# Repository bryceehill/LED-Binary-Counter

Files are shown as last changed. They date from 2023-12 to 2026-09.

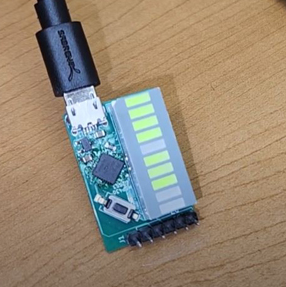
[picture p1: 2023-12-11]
LED_BAR.PNG

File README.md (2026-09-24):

#Introduction

The Montana Tech Binary Counter is a project created by the Electrical Engineering Department.  All files to recreate it are available here.  Potential students can request a binary counter through this link:
https://www.mtech.edu/electrical-engineering/circuit-handout/index.html

To get started plug the binary counter into a computer via a USB cable.  In windows download putty.exe, find the port associated with the counter using "Device Manager" and open that serial port.
Getting started may need some direction.  Watch this video:
https://youtu.be/mpABhzl5tEQ

The current version of the binary counter is the ARM processor version.  You can find all connected files, firmware, designs within this repository.

# LED-Binary-Counter
Public Files for the LED Binary Counter.  Modify, Code, Change, on your own.

There are two versions.  The original one had a MSP430 G2553 as it's controller.  The new version uses an ATSAMD21E15B with added usb utility
Both chips have 10 LEDs that they control.

ARM - ATSAMD21E15B Documentation---------------------------------------------------------------------------

Pinout
PA00 - LED 0
PA01 - LED 1
PA02 - LED 2
PA03 - LED 3
PA04 - LED 4
PA05 - LED 5
PA06 - LED 6
PA07 - LED 7
PA08 - LED 8
PA09 - LED 9
PA16 - PushButton

MSP430 Documentation---------------------------------------------------------------------------------

This respository contains all of the files used to create the Montana Tech LED Bar Graph Counter
The bar graph counter is a piece of SWAG intended for potential students.
There are 10 LEDs controlled by an MSP430 G2553 Microcontroller (TI Look it up)

A PCB was created for use with the QFN-32 package of the G2553
Code was created using code composer studio in C programming language. All files are available
More instructions can be found for new users via the web page:
https://www.mtech.edu/electrical-engineering/circuit-handout/

Potential students can request a free complete system
Pinout of the MSP430 are the following
* 1.0 -
 * 1.1 - RX0  UART Receive
 * 1.2 - TX0  UART Transmit
 * 1.3 - SW1  Pushbutton
 * 1.4 -
 * 1.5 -
 * 1.6 -
 * 1.7 -
 * 2.0 - L8  LED 8
 * 2.1 - L9  LED 9
 * 2.2 -
 * 2.3 -
 * 2.4 -
 * 2.5 -
 * 2.6 -
 * 2.7 -
 * 3.0 - L0  LED 0
 * 3.1 - L1  LED 1
 * 3.2 - L2  LED 2
 * 3.3 - L3  LED 3
 * 3.4 - L4  LED 4
 * 3.5 - L5  LED 5
 * 3.6 - L6  LED 6
 * 3.7 - L7  LED 7

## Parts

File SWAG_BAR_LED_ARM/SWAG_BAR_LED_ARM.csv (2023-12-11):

Source: | C:\Users\CHD\Documents\KiCad\GridLEDv0_1\SWAG_BAR_LED\SWAG_BAR_LED\SWAG_BAR_LED.kicad_sch
Date: | 9/6/2023 4:55:15 PM
Tool: | Eeschema (6.0.1)
Generator: | C:\Program Files\KiCad\6.0\bin\scripting\plugins/bom_csv_grouped_by_value.py
Component Count: | 24
Individual Components:
Item | Qty | Reference(s) | Value | LibPart | Footprint | Datasheet | MANUFACTURER | MAXIMUM_PACKAGE_HEIGHT | PARTREV | STANDARD
 |  | BAR1 | HDSP-4830_2 | LED:HDSP-4830_2 | Display:HDSP-4830 | https://docs.broadcom.com/docs/AV02-1798EN
 |  | C1 | 0.1u | Device:C | Capacitor_SMD:C_0603_1608Metric | ~
 |  | C2 | 0.1u | Device:C | Capacitor_SMD:C_0603_1608Metric | ~
 |  | J1 | Conn_01x06_Male | Connector:Conn_01x06_Male | Connector_PinHeader_2.54mm:PinHeader_1x06_P2.54mm_Vertical | ~
 |  | J3 | USB_B_Micro | Connector:USB_B_Micro | USB:USB_Micro-B_Wuerth_629105150521 | ~
 |  | R1 | 10k | Device:R | Resistor_SMD:R_0603_1608Metric | ~
 |  | R2 | 330 | Device:R | Resistor_SMD:R_0603_1608Metric | ~
 |  | R3 | 330 | Device:R | Resistor_SMD:R_0603_1608Metric | ~
 |  | R4 | 330 | Device:R | Resistor_SMD:R_0603_1608Metric | ~
 |  | R5 | 330 | Device:R | Resistor_SMD:R_0603_1608Metric | ~
 |  | R6 | 330 | Device:R | Resistor_SMD:R_0603_1608Metric | ~
 |  | R7 | 330 | Device:R | Resistor_SMD:R_0603_1608Metric | ~
 |  | R8 | 330 | Device:R | Resistor_SMD:R_0603_1608Metric | ~
 |  | R9 | 330 | Device:R | Resistor_SMD:R_0603_1608Metric | ~
 |  | R10 | 330 | Device:R | Resistor_SMD:R_0603_1608Metric | ~
 |  | R11 | 330 | Device:R | Resistor_SMD:R_0603_1608Metric | ~
 |  | SW1 | PTS636_SM50_SMTR_LFS | SPST_SMD:PTS636_SM50_SMTR_LFS | SW_PTS636_SMT-G_5_CNK | PTS636 SM50 SMTR LFS
 |  | U1 | AP2127N3-1.2 | Regulator_Linear:AP2127N3-1.2 | Package_TO_SOT_SMD:TSOT-23 | https://www.diodes.com/assets/Datasheets/AP2127.pdf
 |  | U2 | SSM6N7002KFU_LF | 2N7002_Dual:SSM6N7002KFU_LF | 6-TSSOP:SOT-363 US6_TOS | SSM6N7002KFU_LF
 |  | U3 | MSP430G2553IRHB32R | MSP430G2553IRHB32R:MSP430G2553IRHB32R | MSP430G2553IRHB32R:IC_MSP430G2553IRHB32R |  | Texas Instruments | 1.00mm | 4223442/B 08/2019 | Manufacturer Recommendations
 |  | U4 | SSM6N7002KFU_LF | 2N7002_Dual:SSM6N7002KFU_LF | 6-TSSOP:SOT-363 US6_TOS | SSM6N7002KFU_LF
 |  | U8 | SSM6N7002KFU_LF | 2N7002_Dual:SSM6N7002KFU_LF | 6-TSSOP:SOT-363 US6_TOS | SSM6N7002KFU_LF
 |  | U9 | SSM6N7002KFU_LF | 2N7002_Dual:SSM6N7002KFU_LF | 6-TSSOP:SOT-363 US6_TOS | SSM6N7002KFU_LF
 |  | U10 | SSM6N7002KFU_LF | 2N7002_Dual:SSM6N7002KFU_LF | 6-TSSOP:SOT-363 US6_TOS | SSM6N7002KFU_LF
Collated Components:
Item | Qty | Reference(s) | Value | LibPart | Footprint | Datasheet | MANUFACTURER | MAXIMUM_PACKAGE_HEIGHT | PARTREV | STANDARD
1 | 1 | BAR1 | HDSP-4830_2 | LED:HDSP-4830_2 | Display:HDSP-4830 | https://docs.broadcom.com/docs/AV02-1798EN
2 | 2 | C1, C2 | 0.1u | Device:C | Capacitor_SMD:C_0603_1608Metric | ~
3 | 1 | J1 | Conn_01x06_Male | Connector:Conn_01x06_Male | Connector_PinHeader_2.54mm:PinHeader_1x06_P2.54mm_Vertical | ~
4 | 1 | J3 | USB_B_Micro | Connector:USB_B_Micro | USB:USB_Micro-B_Wuerth_629105150521 | ~
5 | 1 | R1 | 10k | Device:R | Resistor_SMD:R_0603_1608Metric | ~
6 | 10 | R2, R3, R4, R5, R6, R7, R8, R9, R10, R11 | 330 | Device:R | Resistor_SMD:R_0603_1608Metric | ~
7 | 1 | SW1 | PTS636_SM50_SMTR_LFS | SPST_SMD:PTS636_SM50_SMTR_LFS | SW_PTS636_SMT-G_5_CNK | PTS636 SM50 SMTR LFS
8 | 1 | U1 | AP2127N3-1.2 | Regulator_Linear:AP2127N3-1.2 | Package_TO_SOT_SMD:TSOT-23 | https://www.diodes.com/assets/Datasheets/AP2127.pdf
9 | 5 | U2, U4, U8, U9, U10 | SSM6N7002KFU_LF | 2N7002_Dual:SSM6N7002KFU_LF | 6-TSSOP:SOT-363 US6_TOS | SSM6N7002KFU_LF
10 | 1 | U3 | MSP430G2553IRHB32R | MSP430G2553IRHB32R:MSP430G2553IRHB32R | MSP430G2553IRHB32R:IC_MSP430G2553IRHB32R |  | Texas Instruments | 1.00mm | 4223442/B 08/2019 | Manufacturer Recommendations

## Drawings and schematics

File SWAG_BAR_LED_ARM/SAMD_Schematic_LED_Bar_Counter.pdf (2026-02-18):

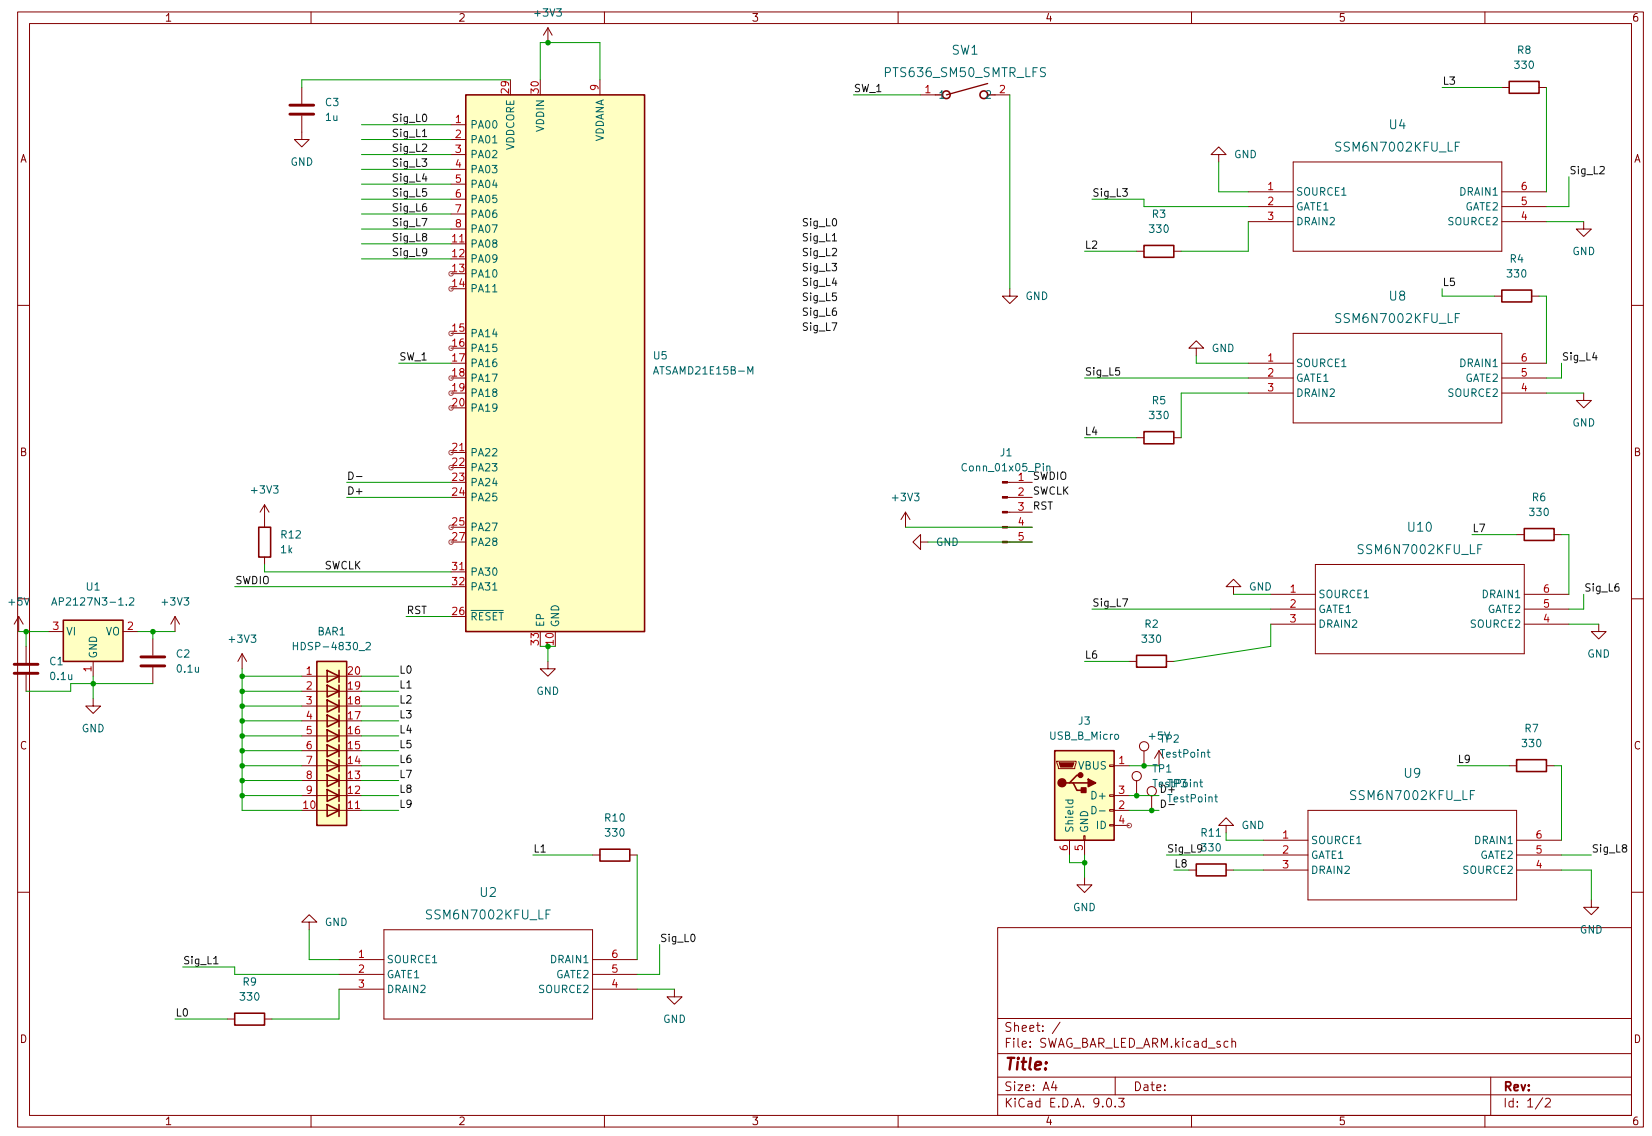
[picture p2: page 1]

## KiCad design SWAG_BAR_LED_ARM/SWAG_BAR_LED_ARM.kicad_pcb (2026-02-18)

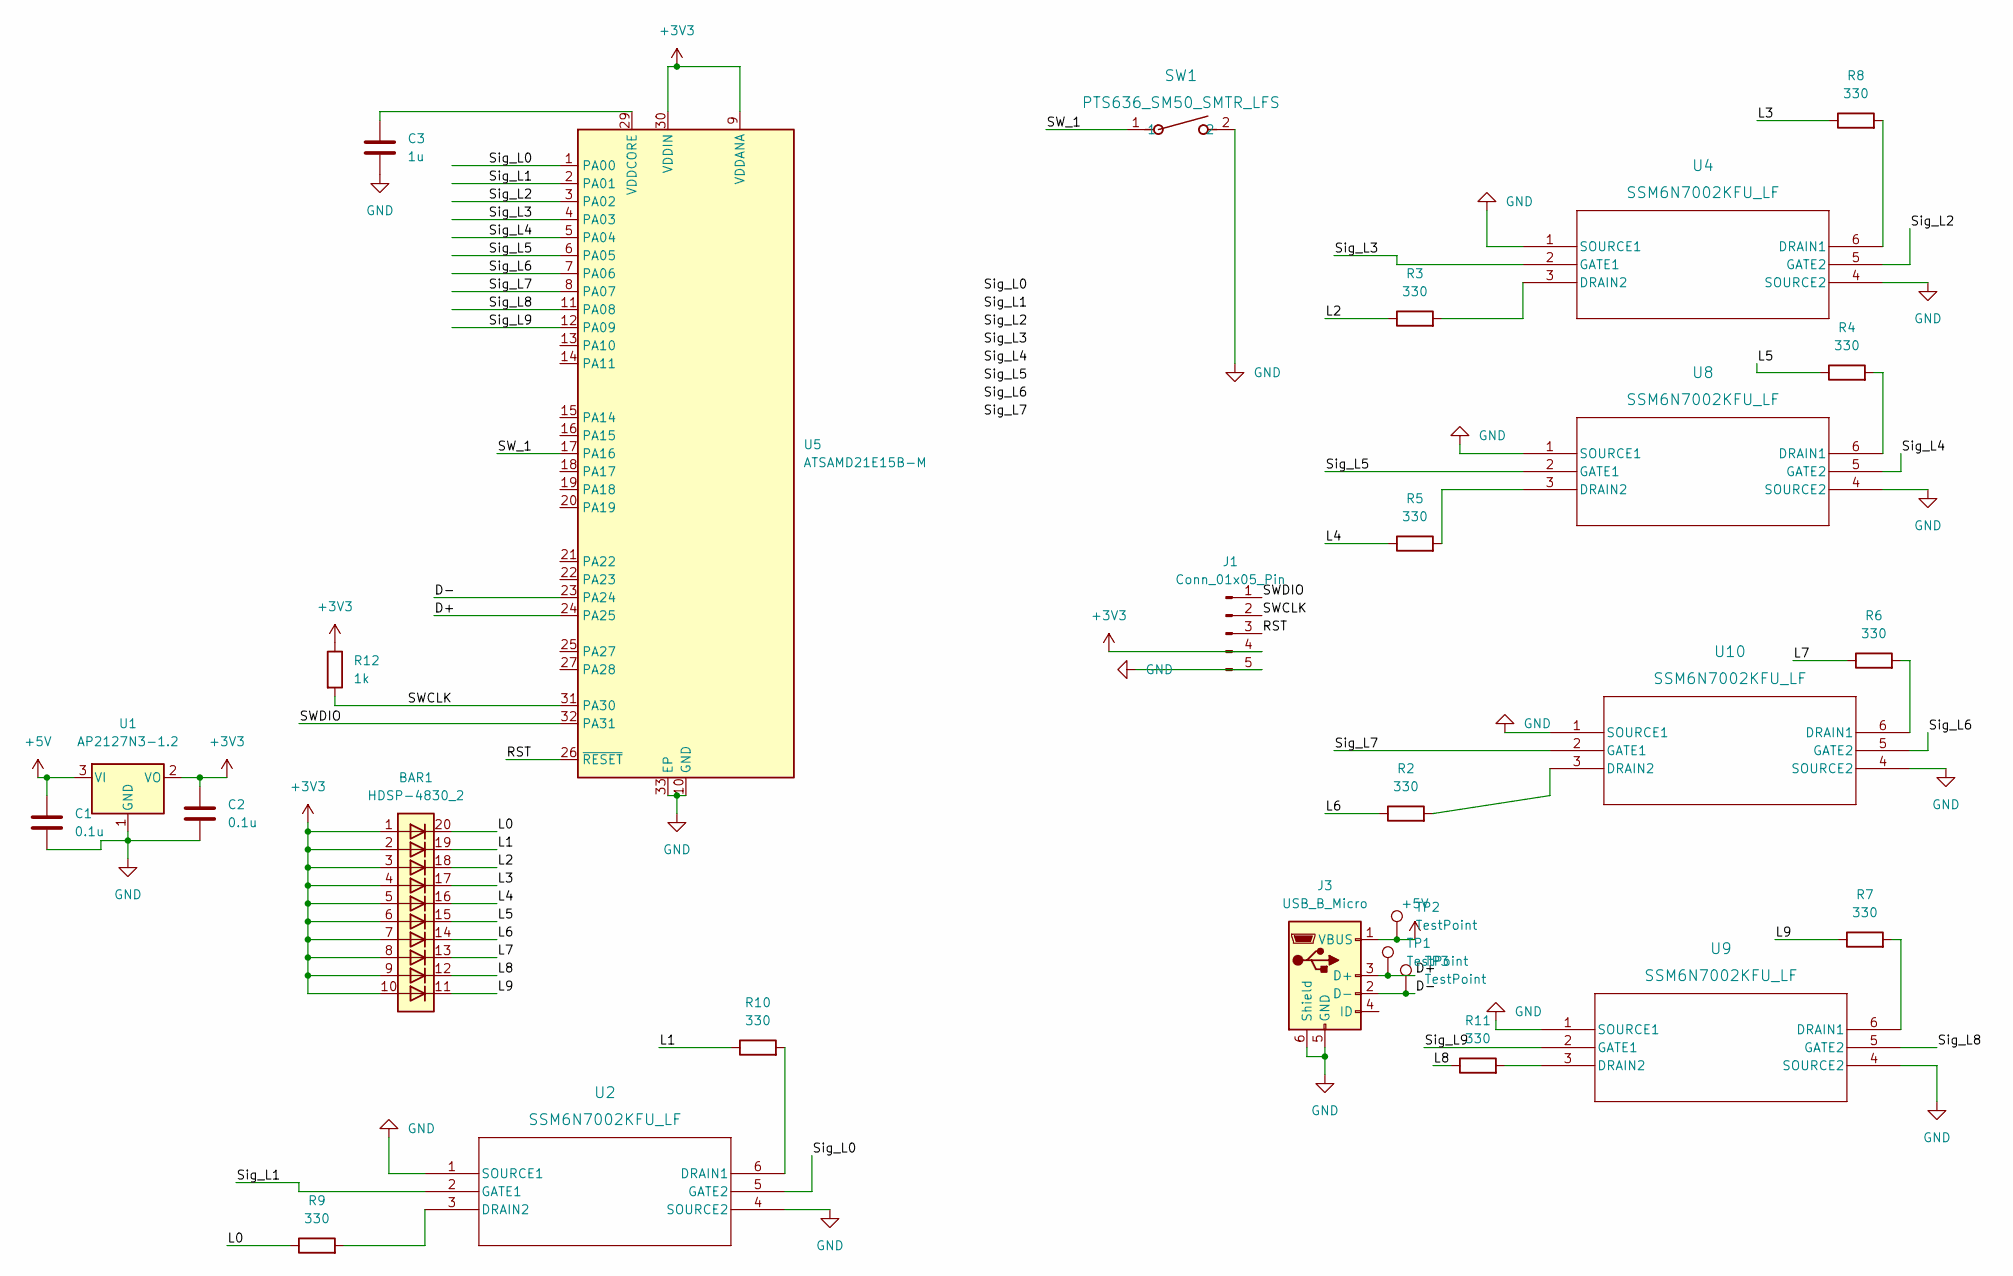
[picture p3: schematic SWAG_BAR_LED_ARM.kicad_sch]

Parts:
BAR1: HDSP-4830_2; HDSP-4830
C1, C2: 0.1u; C_0603_1608Metric
C3: 1u; C_0603_1608Metric
J1: Conn_01x05_Pin; PinHeader_1x05_P2.54mm_Vertical
J3: USB_B_Micro; USB_Micro-B_Wuerth_629105150521
R2, R3, R4, R5, R6, R7, R8, R9, R10, R11: 330; R_0603_1608Metric
R12: 1k; R_0603_1608Metric
SW1: PTS636_SM50_SMTR_LFS; SW_PTS636_SMT-G_5_CNK
TP1, TP2, TP3: TestPoint; TestPoint_Loop_D2.50mm_Drill1.0mm_LowProfile
U1: AP2127N3-1.2; TSOT-23
U2, U4, U8, U9, U10: SSM6N7002KFU_LF; SOT-363 US6_TOS
U5: ATSAMD21E15B-M; QFN-32-1EP_5x5mm_P0.5mm_EP3.6x3.6mm

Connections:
+3V3: BAR1.1 (A), BAR1.2 (A), BAR1.3 (A), BAR1.4 (A), BAR1.5 (A), BAR1.6 (A), BAR1.7 (A), BAR1.8 (A), BAR1.9 (A), BAR1.10 (A), C2.1, J1.4, R12.1, U1.2 (VO), U5.9 (VDDANA), U5.30 (VDDIN)
+5V: C1.1, J3.1 (VBUS), TP2.1, U1.3 (VI)
/D+: J3.3 (D+), TP1.1, U5.24 (PA25)
/D-: J3.2 (D-), TP3.1, U5.23 (PA24)
/L0: BAR1.20 (K), R9.1
/L1: BAR1.19 (K), R10.1
/L2: BAR1.18 (K), R3.1
/L3: BAR1.17 (K), R8.1
/L4: BAR1.16 (K), R5.1
/L5: BAR1.15 (K), R4.1
/L6: BAR1.14 (K), R2.1
/L7: BAR1.13 (K), R6.1
/L8: BAR1.12 (K), R11.1
/L9: BAR1.11 (K), R7.1
/RST: J1.3, U5.26 (~RESET)
/SWCLK: J1.2, R12.2, U5.31 (PA30)
/SWDIO: J1.1, U5.32 (PA31)
/SW_1: SW1.1, U5.17 (PA16)
/Sig_L0: U2.5 (GATE2), U5.1 (PA00)
/Sig_L1: U2.2 (GATE1), U5.2 (PA01)
/Sig_L2: U4.5 (GATE2), U5.3 (PA02)
/Sig_L3: U4.2 (GATE1), U5.4 (PA03)
/Sig_L4: U5.5 (PA04), U8.5 (GATE2)
/Sig_L5: U5.6 (PA05), U8.2 (GATE1)
/Sig_L6: U5.7 (PA06), U10.5 (GATE2)
/Sig_L7: U5.8 (PA07), U10.2 (GATE1)
/Sig_L8: U5.11 (PA08), U9.5 (GATE2)
/Sig_L9: U5.12 (PA09), U9.2 (GATE1)
GND: C1.2, C2.2, C3.2, J1.5, J3.5 (GND), J3.6 (Shield), SW1.2, U1.1 (GND), U2.1 (SOURCE1), U2.4 (SOURCE2), U4.1 (SOURCE1), U4.4 (SOURCE2), U5.10 (GND), U5.28 (GND), U5.33 (EP), U8.1 (SOURCE1), U8.4 (SOURCE2), U9.1 (SOURCE1), U9.4 (SOURCE2), U10.1 (SOURCE1), U10.4 (SOURCE2)
unnamed: R10.2, U2.6 (DRAIN1)
unnamed: R9.2, U2.3 (DRAIN2)
unnamed: R8.2, U4.6 (DRAIN1)
unnamed: R3.2, U4.3 (DRAIN2)
unnamed: C3.1, U5.29 (VDDCORE)
unnamed: R4.2, U8.6 (DRAIN1)
unnamed: R5.2, U8.3 (DRAIN2)
unnamed: R7.2, U9.6 (DRAIN1)
unnamed: R11.2, U9.3 (DRAIN2)
unnamed: R6.2, U10.6 (DRAIN1)
unnamed: R2.2, U10.3 (DRAIN2)

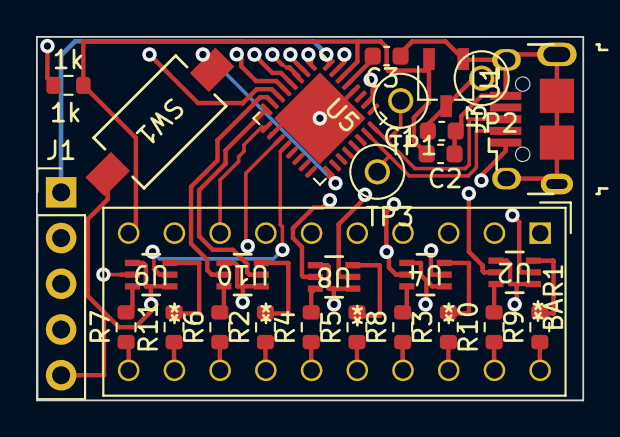
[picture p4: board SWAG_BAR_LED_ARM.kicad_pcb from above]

Board: 4 copper layers, 30.4 x 20.2 mm, 28 parts (0 on the bottom side), 40 nets.

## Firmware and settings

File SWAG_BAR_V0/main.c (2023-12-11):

#include <msp430.h> 
#include "serial_handler.h"
#include "main.h"
#include <stdint.h>

//#include "uart.h"


/**
 * main.c
 * 1.0 -
 * 1.1 - RX0
 * 1.2 - TX0
 * 1.3 - SW1
 * 1.4 -
 * 1.5 -
 * 1.6 -
 * 1.7 -
 * 2.0 - L8
 * 2.1 - L9
 * 2.2 -
 * 2.3 -
 * 2.4 -
 * 2.5 -
 * 2.6 -
 * 2.7 -
 * 3.0 - L0
 * 3.1 - L1
 * 3.2 - L2
 * 3.3 - L3
 * 3.4 - L4
 * 3.5 - L5
 * 3.6 - L6
 * 3.7 - L7
 *
 */

char gridArray[5] = {0x7F, 0x04, 0x18, 0x04, 0x7F};
char currChar = ' ';
int isrCount = 0,ledCount = 0, ledState = 1, countDir = 1;
unsigned int swCount = 0, swBeg=0, uartCount = 0;;

int main(void){
    WDTCTL = WDTPW | WDTHOLD;	// stop watchdog timer
    led_init();
    switch_init();
    timer_ISR_init();
    uart_init(4); // 9600 baud rate = 4 input

    BCSCTL1 = CALBC1_16MHZ;      // Set range
    DCOCTL = CALDCO_16MHZ;      // SMCLK = DCO = 1MHz
    uint8_t c;
    int replyVal=0;
    while(1){
        if(eos_flag){
            replyVal = serial_handler (rx_data_str , 0, rx_flag, tx_data_str);
            if (replyVal)
                uart_write_string(0,replyVal);
            rx_flag = 0;
            eos_flag = 0;
            // Make the timer and count downa nd change the state
            if (ledState<2)
                ledState += 2;
            uartCount = 0;
        }


    }
}



int serial_handler ( char * stringIn, int uartdir,int strLen,char * stringOut){
    // Parse for the initial string and the end string
    volatile int strBeg, strEnd,i,k,byteNum,byteRet,shiftNum,dispShift;
    volatile char tempChar;
    unsigned int dispBits = 0;
    unsigned long convVal = 0, multVal;
    char cmpStr[2],byteOut[5],byteChar[5];
    cmpStr[0]='%';
    cmpStr[1]='*';
    strBeg = strComp(stringIn,cmpStr,strLen+1,2);
    if (strBeg == 0xFFFF)
        return;
    cmpStr[0]=13;
    strEnd = strComp(stringIn,cmpStr,strLen+2,1);
    if (strEnd == 0xFFFF)
        return;
    if (stringIn[strBeg+2] == 'b'){  // binary value entered
        for (k=0;k<(strLen-strBeg-1);k++){
            if (stringIn[strEnd-k-1]=='1')
                dispBits |= (1<<k);


        }
        dispBits = swapMsb(dispBits);
        P3OUT = ((dispBits)>>6)&0xFF;
        P2OUT &=~ (BIT0+BIT1);
        dispBits =((dispBits&0xC000)>>14);
        P2OUT |= dispBits;
        return 0;
    }
    if (stringIn[strBeg+2] == 'o'){  // octal value entered
        for (k=0;k<(strLen-strBeg-4);k++){
            convVal = stringIn[strEnd-1-k] - '0';
            dispBits |= convVal<<(k*3);
        }

        dispBits = swapMsb(dispBits);
        P3OUT = ((dispBits)>>6)&0xFF;
        P2OUT &=~ (BIT0+BIT1);
        dispBits =((dispBits&0xC000)>>14);
        P2OUT |= dispBits;
    }
    if (stringIn[strBeg+2] == 'd'){  // decimal value entered
        multVal = 1;
        for (k=0;k<(strLen-strBeg-4);k++){
            convVal = stringIn[strEnd-1-k] - '0';
            dispBits += convVal*(multVal);
            multVal*=10;
        }

        dispBits = swapMsb(dispBits);
        P3OUT = ((dispBits)>>6)&0xFF;
        P2OUT &=~ (BIT0+BIT1);
        dispBits =((dispBits&0xC000)>>14);
        P2OUT |= dispBits;
        return 0;
    }
    if (stringIn[strBeg+2] == 'x'){  // Hex value entered
        for (k=0;k<(strLen-strBeg-4);k++){
            if (stringIn[strEnd-1-k]<='9'){
                convVal = stringIn[strEnd-1-k] - '0';
            }
            else if(stringIn[strEnd-1-k]<='F'){
                convVal = stringIn[strEnd-1-k] - 'A'+10;
            }
            else if(stringIn[strEnd-1-k]<='4'){
                convVal = stringIn[strEnd-1-k] - 'a'+10;
            }

            dispBits += convVal<<(k*4);
        }

        dispBits = swapMsb(dispBits);
        P3OUT = ((dispBits)>>6)&0xFF;
        P2OUT &=~ (BIT0+BIT1);
        dispBits =((dispBits&0xC000)>>14);
        P2OUT |= dispBits;
    }
    return 0;
}

void convNibble(char * stringIn,char * byteOut, int num2Conv){
    // blindly converts two nibbles embedded in two bytes to a byte raw format
    int k;
    //    volatile char C1, C2;
    //    volatile int tempVal=0;
    for(k = 0;k<num2Conv;k++){
        //        C1=stringIn[k*2];
        //        C2 = stringIn[k*2+1];

        //        tempVal = (stringIn[k*2]-0x30)*10 + (stringIn[k*2+1]-0x30);
        byteOut[k] = (stringIn[k*2]-0x30)*10 + (stringIn[k*2+1]-0x30);
    }
}

void num2Char2Digit(int valIn,char * stringIn){
    //convert to a 2 digit char string.  Only 2 digits
    int tempVal=0;
    //    if (valIn<10){
    //        stringIn[0]='0';
    //        stringIn[1]=0x30+valIn;
    //    }
    tempVal = valIn/10;
    stringIn[0]=tempVal+0x30;
    valIn -= 10*tempVal;
    stringIn[1] = valIn+0x30;

}

int twoCharConv (char * stringIn){
    // simply and blindly creates a two digit int from two digit char
    return (stringIn[0]-0x30)*10+(stringIn[1]-0x30);
}

int strComp (char * stringIn, char * strPattern, int stringLen, int patternLen){
    // returns a value of where in the string the first occurance happens
    int i,k,diffVal;
    for (k=0;k<stringLen-patternLen;k++){
        diffVal = 0;
        for (i = 0;i<patternLen; i++){
            if (stringIn[k+i] != strPattern[i])
                diffVal++;
        }
        if (diffVal == 0)
            return k;
    }
    return 0xFFFF;  // no pattern detected

}





void led_init(void){
    P2DIR |= (BIT0+BIT1);   // Annodes as outputs  (Active Low)
    P2OUT |= (BIT0+BIT1);        // Annodes all off
    // PWM pin on (for brightness) On
    P3DIR |= (BIT0+BIT1+BIT2+BIT3+BIT4+BIT5+BIT6+BIT7);  // Cathodes all as outputs
    P3OUT |= (BIT0+BIT1+BIT2+BIT3+BIT4+BIT5+BIT6+BIT7);  // Cathodes all low (Active high)

}

void timer_ISR_init(void){
    TA1CCTL0 = CCIE;                             // CCR0 interrupt enabled
    TA1CCR0 = 0;
    TA1CTL = TASSEL_2 + MC_2;                  // SMCLK, contmode

    _BIS_SR( GIE);                 // Enter LPM0 w/ interrupt
}

#pragma vector=PORT1_VECTOR
__interrupt void Port_1(void){
    if (P1IFG & BIT3){                   // RX has ensued
        if (P1IES & BIT3){
            swBeg = swCount;
        }
        else{
            if ((swCount-swBeg)>10000){
                //long press
                countDir*=-1;
                ledState = 1;
            }
            else {  // short press
                ledState ^= 1;
            }
        }
        P1IES ^= (BIT3);
        P1IFG &=~ BIT3;
    }
}
// Timer A0 interrupt service routine
#pragma vector=TIMER1_A0_VECTOR
__interrupt void Timer_A1 (void)
{
    char outstr[] = "Decimal Value:     ";
    char tempstr[7];
    int tempVal, k;
    isrCount++;
    swCount++;
    if (ledState >1){
    uartCount++;
    if (uartCount>60000)
        ledState-=2;
    }

    if (ledState==1){
        if (isrCount>4000){
            ledCount+=countDir;
            tempVal = swapMsb(ledCount);
            P3OUT = (tempVal>>6)&0xFF;
            P2OUT &=~ (BIT0+BIT1);
            tempVal =((tempVal&0xC000)>>14);
            P2OUT |= tempVal;
            isrCount=0;
            num2str(ledCount&(0x03FF), tempstr);
            outstr[15]=tempstr[2];
            outstr[16]=tempstr[3];
            outstr[17]=tempstr[4];
            outstr[18]=tempstr[5];
            for (k = 0;k<20;k++){
                tx_data_str[k]=outstr[k];
            }
            uart_write_fast_string(0, 19);
        }
    }

    TA1CCR0 +=1000;                            // Add Offset to CCR0
}

int swapMsb(int valin){
    int k;
    long outVal = 0;
    for(k=0;k<16;k++){
        if (valin&(1<<k))
            outVal |= (0x8000>>k);

    }
    return outVal;
}


void switch_init(void){
    P1DIR &=~ (BIT3);  // INputs for switches
    P1OUT |= (BIT3);   // Pull-UP for switches
    P1REN |= (BIT3);   // Pulling resistors for switches
    P1IE |=(BIT3);   // Hardware interrupt P1 switches
    P1IES |=(BIT3);   // High to low edge trigger
    P1IFG &= ~ (BIT3);
    _BIS_SR( GIE);                 // Global interrupt enable
}


void num2str(int val, char * outStr){
    volatile int temp,prev;
    unsigned int divider=10000;
    volatile int n=1,z=0,neg=0;
    outStr[0]='0';
    if (val<0){
        neg=1;
        val=val*(-1);
        outStr[0]='-';
    }
    prev=0;
    for(n=1;n<6;n++){
        temp=(val-prev)/divider;


        outStr[n]=temp+0x30;
        prev=prev+(temp*divider);


        divider=divider/10;
    }

}

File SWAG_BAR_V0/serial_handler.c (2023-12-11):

/*
 * uart_control.c
 *
 *  Created on: Jul 28, 2014
 *      Author: BHill
 */
#include  "msp430.h"
#include "serial_handler.h"
//#define uart_max 100
#define i2c_max  12

unsigned char tx_data_str[uart_max], rx_data_str[uart_max], rx_flag=0, dec_str[7], eos_flag=0;
char dec_char[6];
int tx_ptr,e_tx_ptr;




void uart_init(int br){
    volatile int temp=0;
    //Set baud rate to 300, 1200, 2400, 4800, 9600, 19200, 38400, 57600, 115200, 230400, 460800, 921600
    // use index of 0 1 2 3... corresponding to the rates above
    volatile unsigned int brvec[]={0x55, 0x15, 0x0B, 0x05, 0x83, 0x41, 0xA1, 0x16, 139, 69, 35, 17};
    volatile unsigned int hrvec[]={0xD0,0x34,0x1A,0x0D,6,3,1,1,0,0,0,0};
    BCSCTL1 = CALBC1_16MHZ;                    // Set DCO
    DCOCTL = CALDCO_16MHZ;
    P1SEL |= (BIT1+BIT2);                             // P3.4,5 = USCI_A0 TXD/RXD
    P1SEL2 |= (BIT1+BIT2);
    //	UCA0CTL1 |= UCSWRST;
    UCA0CTL1 |= UCSSEL_2;                     // SMCLK
    UCA0BR0 = brvec[br];
    UCA0BR1 = hrvec[br];
    UCA0MCTL = UCBRS0;                        // Modulation UCBRSx = 1
    UCA0CTL1 &= ~UCSWRST;                     // **Initialize USCI state machine**
    IE2 |= UCA0RXIE;                          // Enable USCI_A0 RX interrupt
    __bis_SR_register(GIE);       			// interrupts enabled
}

void uart_write_string(int vals, int vale){
    int i;									// writes a string from global variable tx_data_str.  vals is starting pointer and vale is the ending value
    for(i=vals;i<vale;i++){
        while (!(IFG2&UCA0TXIFG));
        UCA0TXBUF=tx_data_str[i];
    }
    while (!(IFG2&UCA0TXIFG));
    UCA0TXBUF='\n';
    while (!(IFG2&UCA0TXIFG));
    UCA0TXBUF='\r';
}

void uart_write_fast_string(int vals, int vale){
    tx_ptr=vals;								// writes a string from global variable tx_data_str.  vals is starting pointer and vale is the ending value
    e_tx_ptr=vale;								//  Uses interrupts to send out bytes
    UCA0TXBUF=tx_data_str[tx_ptr];
    IE2 |= UCA0TXIE;

}


#pragma vector=USCIAB0TX_VECTOR
__interrupt void USCI0TX_ISR(void)
{
    if (IE2&UCA0TXIE){									//portion of uart_write_fast_string
        tx_ptr++;
        if (tx_ptr<e_tx_ptr)
            UCA0TXBUF=tx_data_str[tx_ptr];
        else if (tx_ptr==e_tx_ptr){
            UCA0TXBUF='\n';
        }
        else{
            UCA0TXBUF='\r';
            IE2 &=~ UCA0TXIE;
        }
    }
    else{



    }



}

//  Place data in RX-buffer and set flag
#pragma vector=USCIAB0RX_VECTOR
__interrupt void USCI0RX_ISR(void)
{
    volatile char temp;
    if(IFG2 & UCA0RXIFG){							// Receive data on UART
        rx_data_str[rx_flag]=UCA0RXBUF;				// data is stored in rx_data_str
        temp=rx_data_str[rx_flag];
        while (!(IFG2&UCA0TXIFG));
        //	UCA0TXBUF=temp;
        if (rx_data_str[rx_flag]=='\r')				// new line or carriage return set eos_flag global variable
            eos_flag=1;
        if (rx_data_str[rx_flag]=='\n')
            eos_flag=1;
        rx_flag++;
        if (rx_flag>uart_max){							// maximum of characters starts at the beginning again
            rx_flag=1;
        }
    }
}

char uart_get_char(int num){
    return rx_data_str[num];
}
void uart_set_char(char tx_data,int num){
    tx_data_str[num]=tx_data;
}


void conv_hex_dec(int val){
    volatile int temp,prev;
    unsigned int divider=10000;
    volatile int n=1,z=0,neg=0;
    dec_str[0]='0';
    if (val<0){
        neg=1;
        val=val*(-1);
        dec_str[0]='-';
    }
    prev=0;
    for(n=1;n<6;n++){
        temp=(val-prev)/divider;


        dec_str[n]=temp+0x30;
        prev=prev+(temp*divider);


        divider=divider/10;
    }

}

void unsigned_conv_hex_dec(int val){
    volatile unsigned int temp,prev;
    unsigned int divider=10000;
    volatile unsigned int n=1,z=0,neg=0;
    dec_str[0]='0';
    prev=0;
    for(n=1;n<6;n++){
        temp=(val-prev)/divider;


        dec_str[n]=temp+0x30;
        prev=prev+(temp*divider);


        divider=divider/10;
    }

}

int conv_dec_hex ( void ){
    volatile int num,k,temp;
    num=0;
    for (k=1;k<6;k++){
        num*=10;
        temp=dec_char[k];
        if (dec_char[k]>0x39)
            return 0x7FFF;
        if (dec_char[k]<0x30)
            return 0x7fff;
        num+=(dec_char[k]-0x30);
    }
    if (dec_char[0]=='-')
        num=num*(-1);
    return num;
}

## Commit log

2023-12-11 KiCAD File upload
    Initial files for the SWAG Bar LED from KiCAD V7
    [SWAG_BAR_LED.csv, SWAG_BAR_LED.kicad_pcb, SWAG_BAR_LED.kicad_sch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]
2023-12-11 LED Bar Picture for reference
    Just a picture
2023-12-11 MSP430 CCS Code
    Code for the LED Bar Counter
